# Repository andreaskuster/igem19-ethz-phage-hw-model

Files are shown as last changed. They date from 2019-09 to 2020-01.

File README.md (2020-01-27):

# iGEM ETHZ Logo iGEM ETH Zurich - iGEM 19 ETHZ Logo Libraries for Personalized Phage Therapy   

## Project Abstract
Antibiotic resistant pathogens are a major threat to global health. Emerging superbugs are rapidly becoming resistant to available antibiotics, while the discovery of new antibiotics is falling behind. Phage therapy offers a potential solution that has achieved remarkable successes. However, it is limited by the number of pathogens that can be targeted by available natural phages. To address this limitation, we aim to increase the range of phage specificities. Host specificity is influenced by the affinity of the phage’s binding protein to the bacterial surface. We developed a system that integrates random codons in phage genomes at any locus of interest. This allows for the formation of phage libraries with novel binding proteins that alter the host spectrum. Our bioreactor selects and evolves the best variants. The observed phage-host interactions can be used to further improve library design. Our system could be the basis for personalized treatment of bacterial infections. 
We are currently testing three approaches to generate these libraries.
* Yeast assembly: a plasmid containing the T7 genome is assembled by homologous recombination in yeast and a library of randomized oligos is inserted into variable region of tail fiber protein.
* Recombineering: A randomised sequence present on a plasmid is inserted into the tail fiber gene in vivo by using E. coli's homologous recombination machinery.
* In vitro: The tail fiber variable regions are ligated to the T7 genome in vitro by Gibson assembly. 

## Project Trailer
T007 - License to Lyse - iGEM 2019 ETH Zurich - Trailer (https://www.youtube.com/watch?v=lpeFW6eoZ5g?autoplay=1)

## Hardware Reactor Abstract
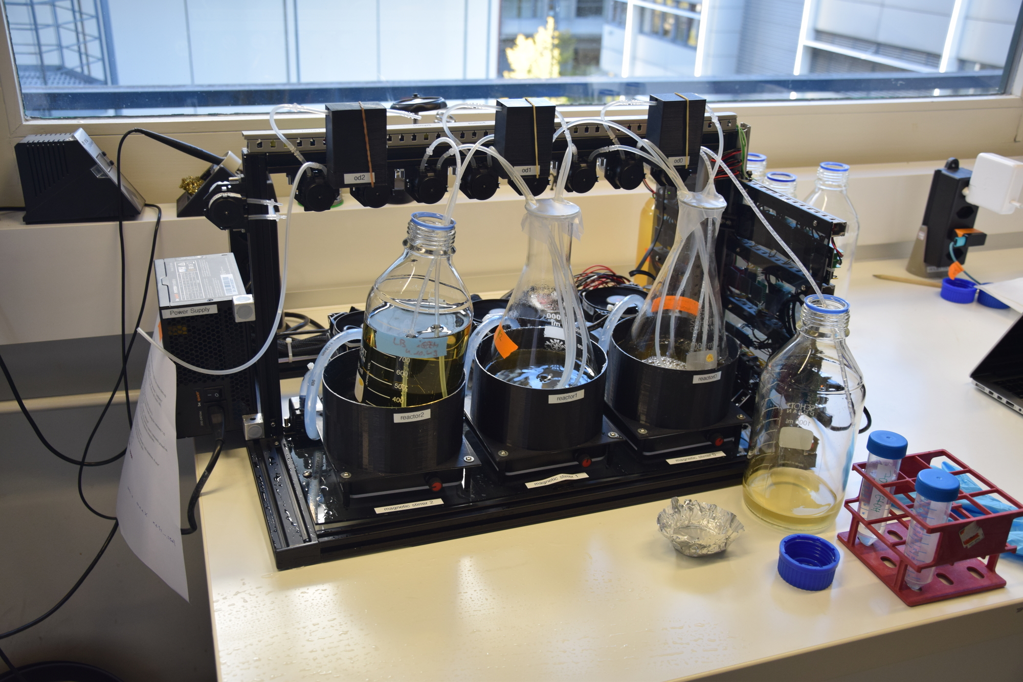
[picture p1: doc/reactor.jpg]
Hardware Reactor


To ensure the clinical relevance of our library, the rapid selection of the best phage variants is necessary and ensured by our bioreactor. Three flasks for cell growth each have integrated temperature control and peristaltic pumps on top of continuous OD measurement using our self-built OD sensors. This enables the cultivation of bacteria under controlled OD profiles. Real-time data from ongoing experiments is fed into our model to predict host concentrations and adjust growth conditions accordingly. User-friendly software allows the implementation of other experimental setups with custom parameters and monitoring mechanisms. Remote access and alerts permit long-term experiments. Our prototype was of great use for our own long-term and large volume experiments which led to multiple iterations of hardware and software improvements. To allow others to benefit from our design, we extensively documented the hardware and software. This bioreactor offers a cost-efficient solution to perform complex experimental designs with ease.

## Table of content
* [Case Study](#case-study-recombineering-library-experiment)
    * [Setup](#experiment-setup)
    * [Result](#result)
* [Hardware Reactor](#hardware-reactor)
    * [Hardware Overview](#hardware-overview)
    * [Hardware Components](#hardware-components)
    * [Software Overview](#software-overview)
        * [Online Optical Density Sensor](#)
        * [Reactor Temperature Control](#)
* [Software Model](#software-model)
    * [General](#general)
    * [Yeast Assembly](#phage-hw-model-1-yeast-assembly)
    * [Recombineering](#phage-hw-model-2-recombineering)

## Case Study: Recombineering Library Experiment
The goal of this case study is to show the reader a real-world usage scenario of the reactor system. Furthermore, it emphasizes the advantage of a fully automated and self-regulating experiment setup.

### Experiment Setup

Reactor Configuration

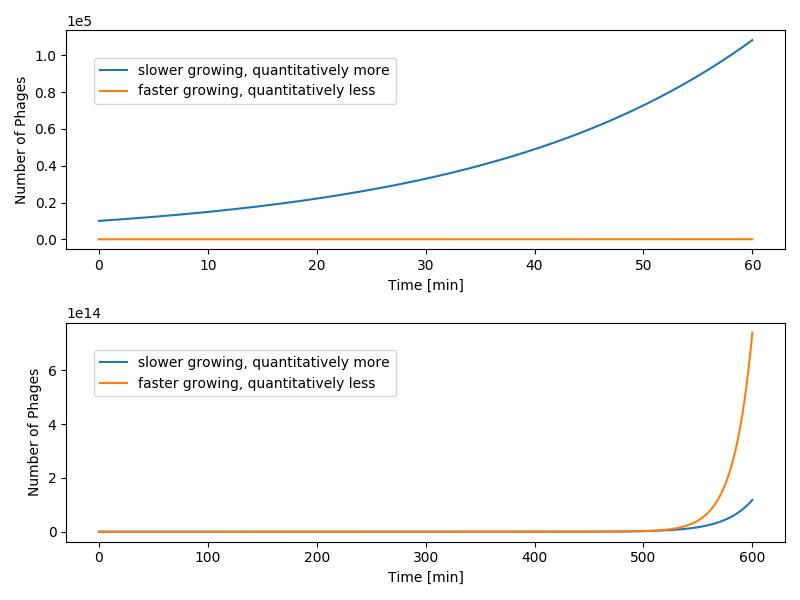
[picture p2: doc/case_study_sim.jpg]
Growth Simulation


### Result
 
Plate Result

## Software Model

### General

### Phage HW Model #1: Yeast Assembly
...
### Phage HW Model #2: Recombineering
...

## Hardware Reactor

### Hardware Overview
Reactor Hardware Overview

### Hardware Components

#### Computer: Raspberry Pi 3B+
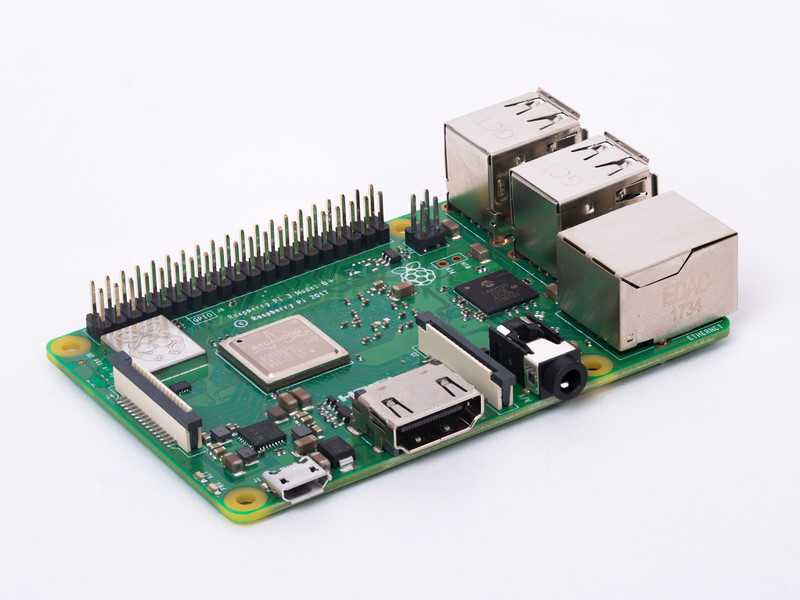
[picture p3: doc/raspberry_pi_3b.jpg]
Raspberry Pi 3B+


[Datasheet](hardware/devices/drivers/hw/datasheets/raspberry_pi_3b.pdf)
[Source](https://www.raspberrypi.org/)

#### Water Temperature Sensor: DS18B20
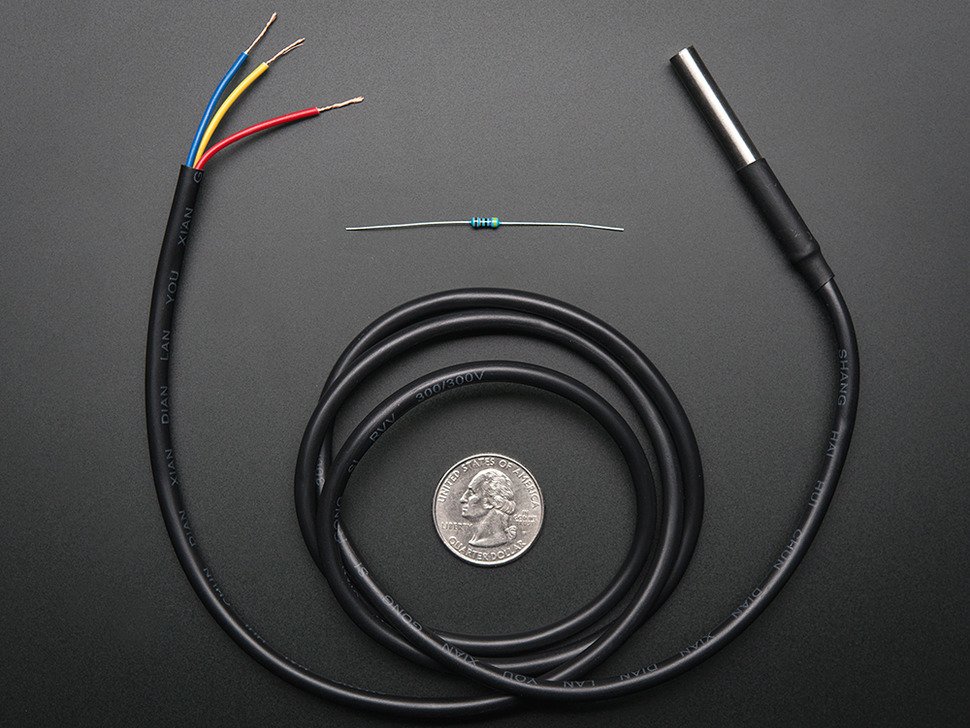
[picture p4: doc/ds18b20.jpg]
DS18B20


[Datasheet](hardware/devices/drivers/hw/datasheets/DS18B20.pdf)
[Source](https://www.adafruit.com/product/381)

#### Thermoelectric Peltier Element: TEC1-12715
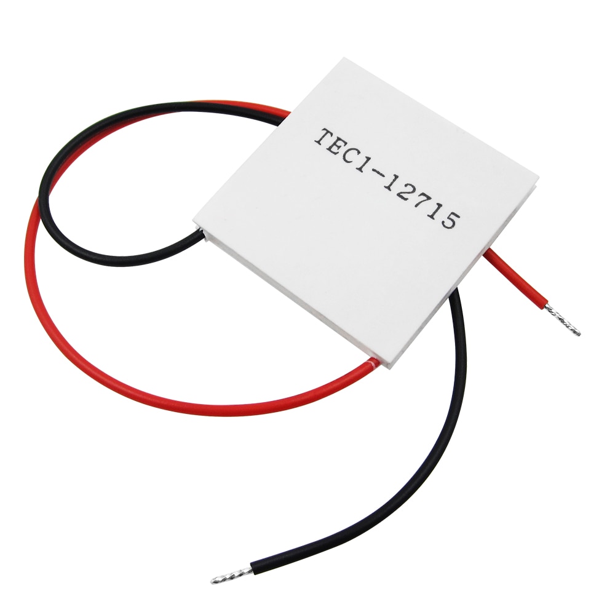
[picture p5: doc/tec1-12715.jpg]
TEC1-12715


[Datasheet](hardware/devices/drivers/hw/datasheets/TEC1_12715.pdf)
[Source](https://www.aliexpress.com/)

#### Electronic Speed Controller ESC
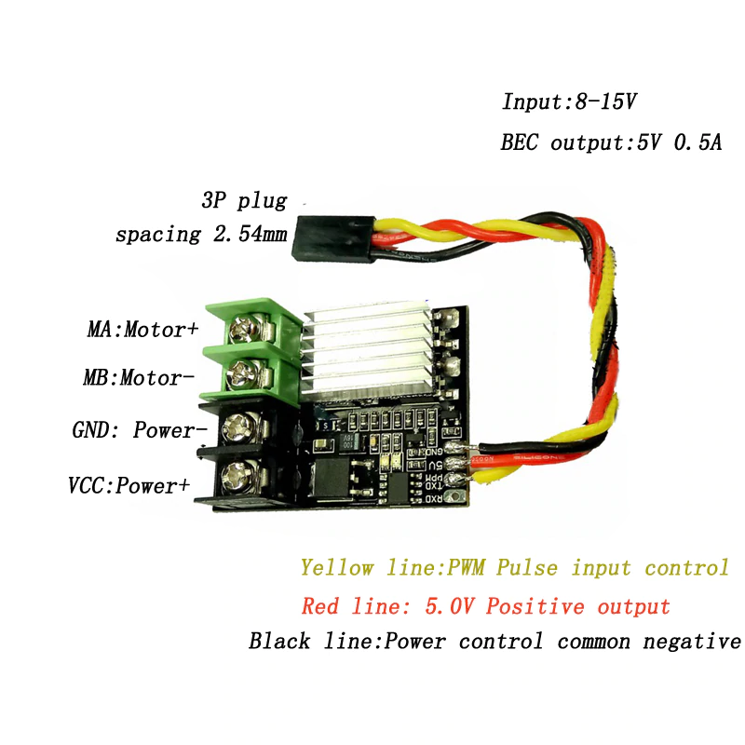
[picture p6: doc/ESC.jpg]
ESC


[Datasheet](hardware/devices/drivers/hw/datasheets/ESC.pdf)
[Source](https://www.aliexpress.com/)

#### Microprocessor: Arduino Nano
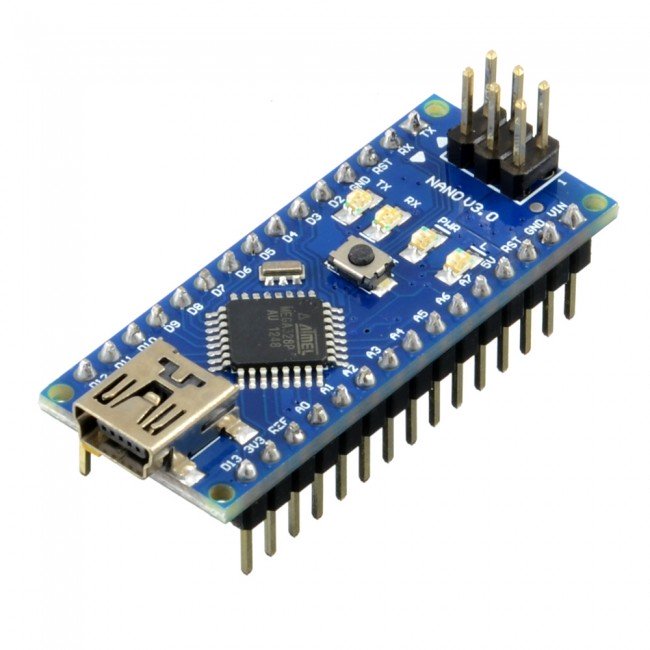
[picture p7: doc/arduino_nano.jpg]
Arduino Nano


[Datasheet](hardware/devices/drivers/hw/datasheets/a.pdf)
[Source](https://core-electronics.com.au/)

#### Ambient Temperature and Pressure Sensor: BME280
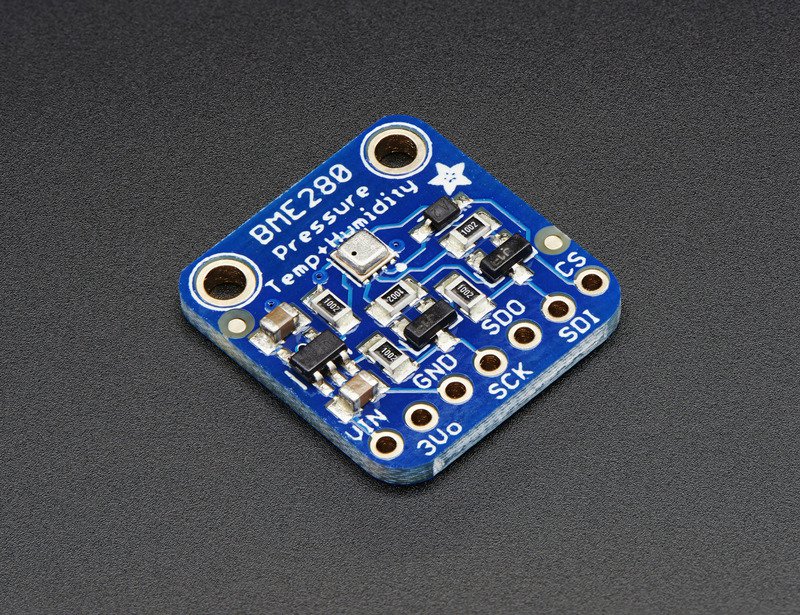
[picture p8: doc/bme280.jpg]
BME280


[Datasheet](hardware/devices/drivers/hw/datasheets/BME280.pdf)
[Source](https://learn.adafruit.com/adafruit-bme280-humidity-barometric-pressure-temperature-sensor-breakout)

#### 8 Channel Input/Output Port Extender: PCF8574
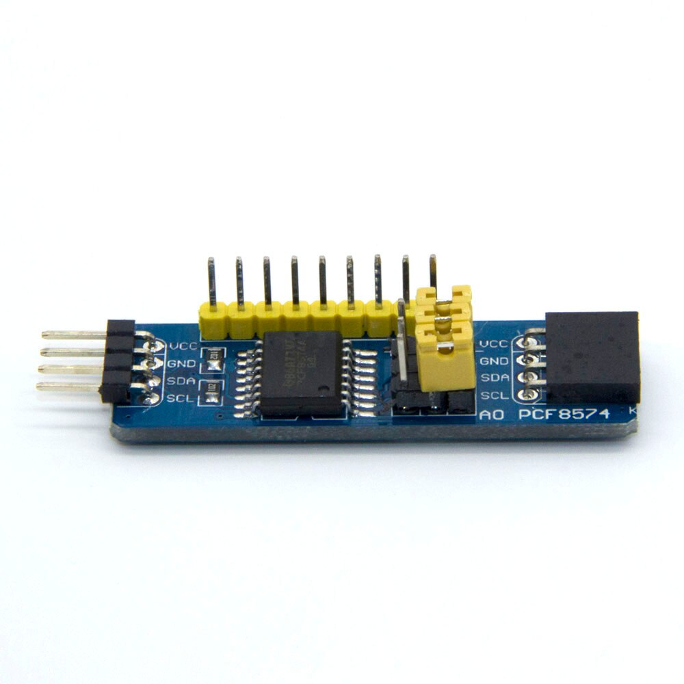
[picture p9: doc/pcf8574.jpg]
PCF8574


[Datasheet](hardware/devices/drivers/hw/datasheets/PCF8574.pdf)
[Source](https://www.aliexpress.com/)

#### Light Emitting Diode LED: TLCY5800
TLCY5800

[Datasheet](hardware/devices/drivers/hw/datasheets/TLCY5800.pdf)
[Source](https://www.distrelec.ch/de/led-gelb-mm-vishay-tlcy5800/p/30105848)

#### I2C Bus Multiplexer: TCA9548A
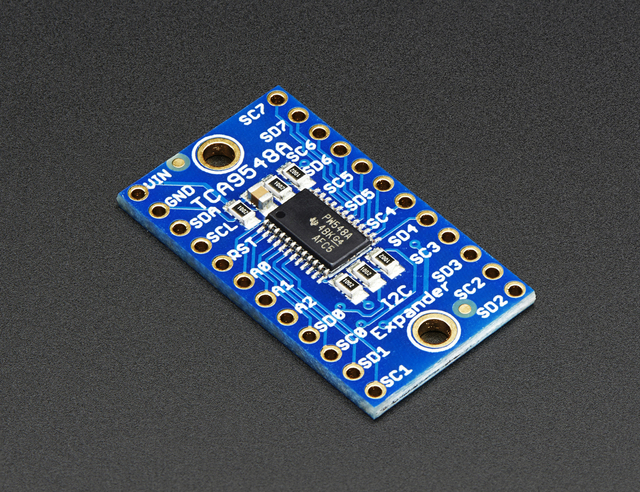
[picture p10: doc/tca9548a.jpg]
TCA9548A


[Datasheet](hardware/devices/drivers/hw/datasheets/TCA9448A.pdf)
[Source](https://learn.adafruit.com/adafruit-tca9548a-1-to-8-i2c-multiplexer-breakout/overview)

#### High Dynamic Range Digital Light Sensor: TSL2591
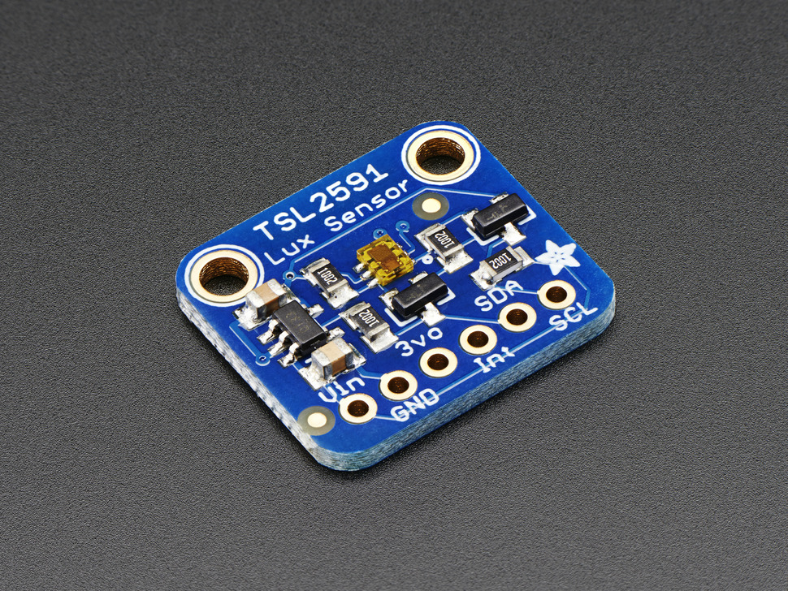
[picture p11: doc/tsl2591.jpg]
TSL2591


[Datasheet](hardware/devices/drivers/hw/datasheets/TSL2591.pdf)
[Source](https://www.adafruit.com/product/1980)

#### 16 Channel Pulse Width Modulation Module: PCA9685
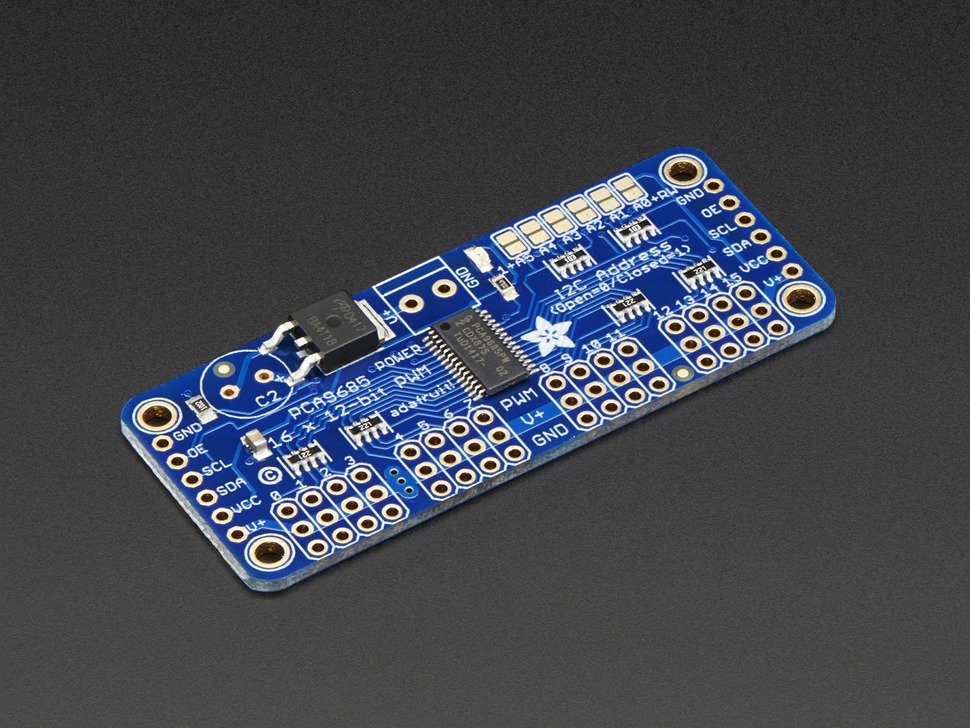
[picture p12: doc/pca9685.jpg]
PCA9685


[Datasheet](hardware/devices/drivers/hw/datasheets/PCA9685.pdf)
[Source](https://www.adafruit.com/product/815)

#### Optocoupler: TLP281
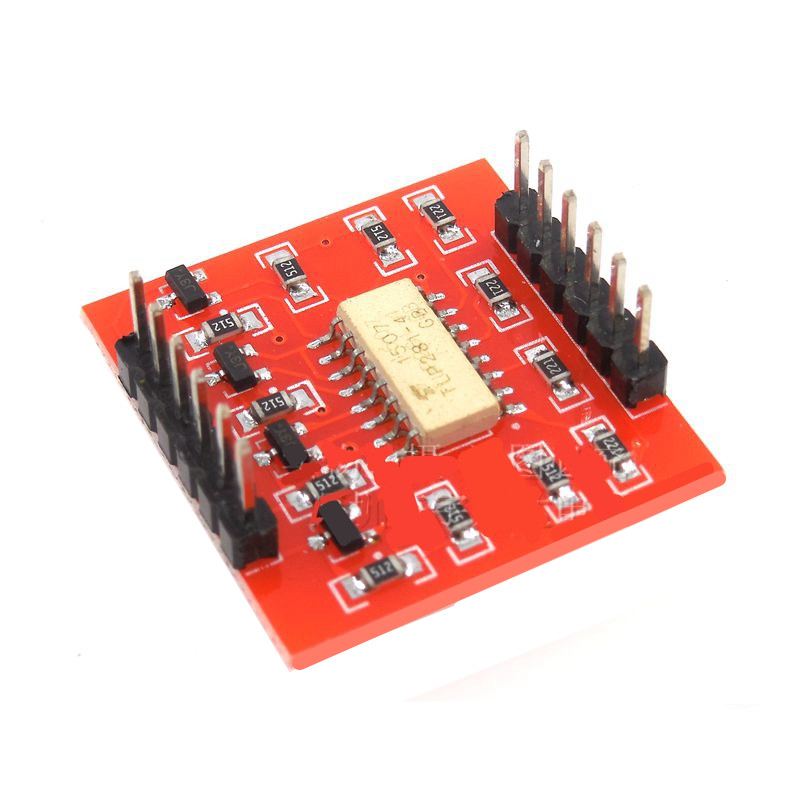
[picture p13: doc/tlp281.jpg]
TLP281


[Datasheet](hardware/devices/drivers/hw/datasheets/TLP281-4.pdf)
[Source](https://www.aliexpress.com/)

#### Magnetic Stirrer
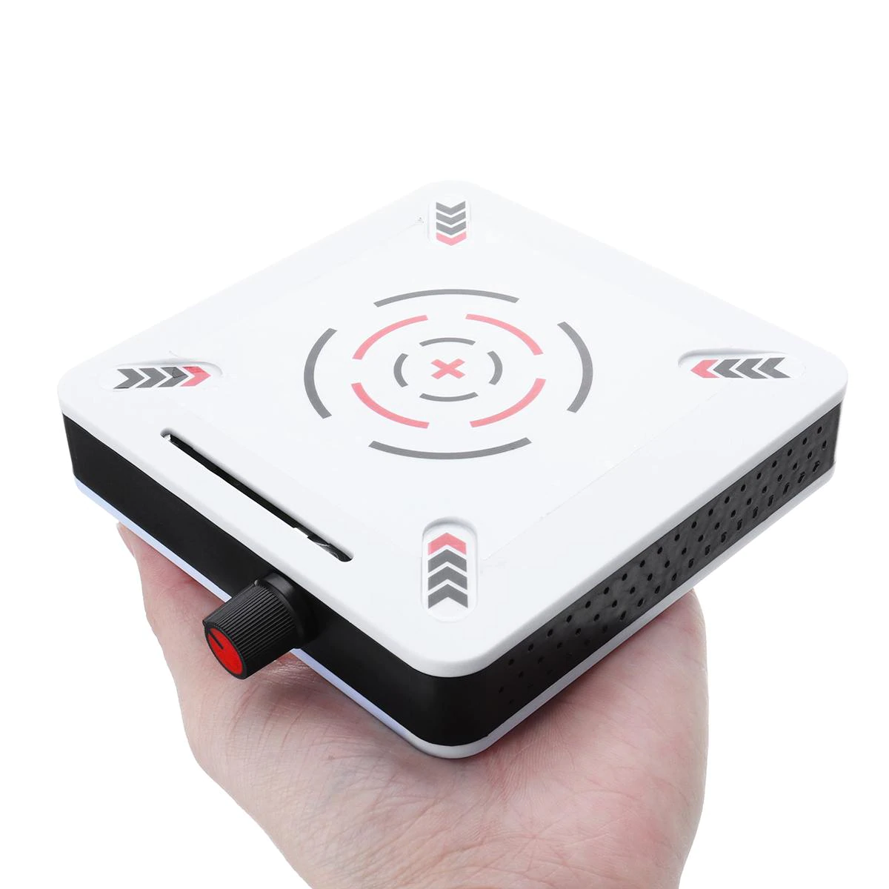
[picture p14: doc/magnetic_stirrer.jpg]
Magnetic Stirrer


[Datasheet](hardware/devices/drivers/hw/datasheets/magnetic_stirrer.pdf)
[Source](https://www.aliexpress.com/)

#### CPU PC Fan
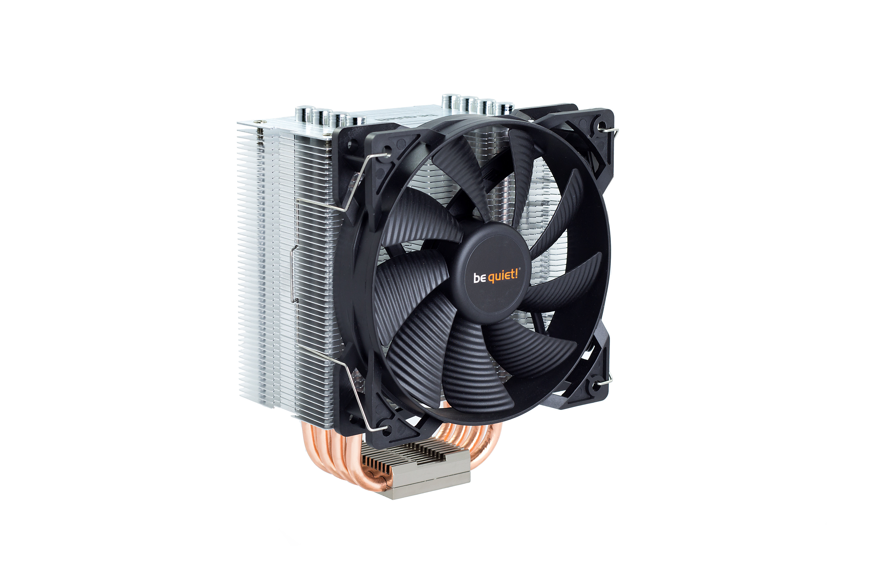
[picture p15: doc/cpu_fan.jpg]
CPU PC Fan


[Datasheet](hardware/devices/drivers/hw/datasheets/cpu_fan.pdf)
[Source](https://www.bequiet.com/en)

#### Water Pump
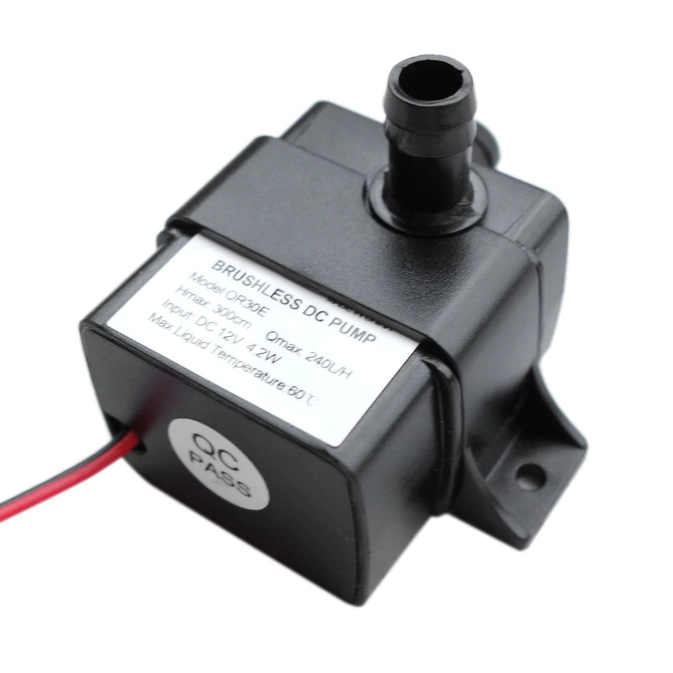
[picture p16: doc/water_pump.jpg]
Water Pump


[Datasheet](hardware/devices/drivers/hw/datasheets/water_pump.pdf)
[Source](https://www.aliexpress.com/)

#### Peristaltic Pump
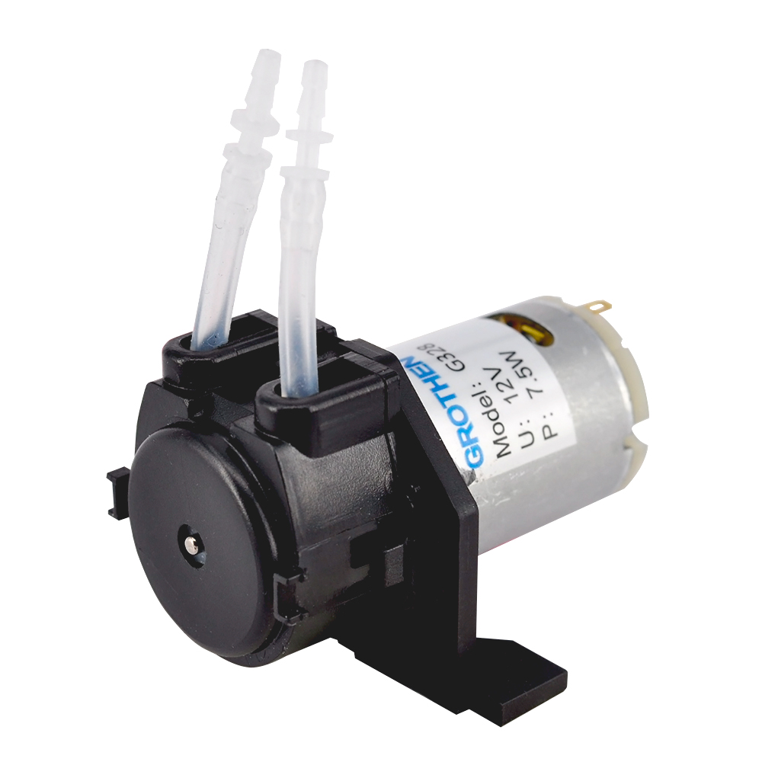
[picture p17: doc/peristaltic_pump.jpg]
Peristaltic Pump


[Datasheet](hardware/devices/drivers/hw/datasheets/peristaltic_pump.pdf)
[Source](https://www.aliexpress.com/)

#### Mosfet Transistor
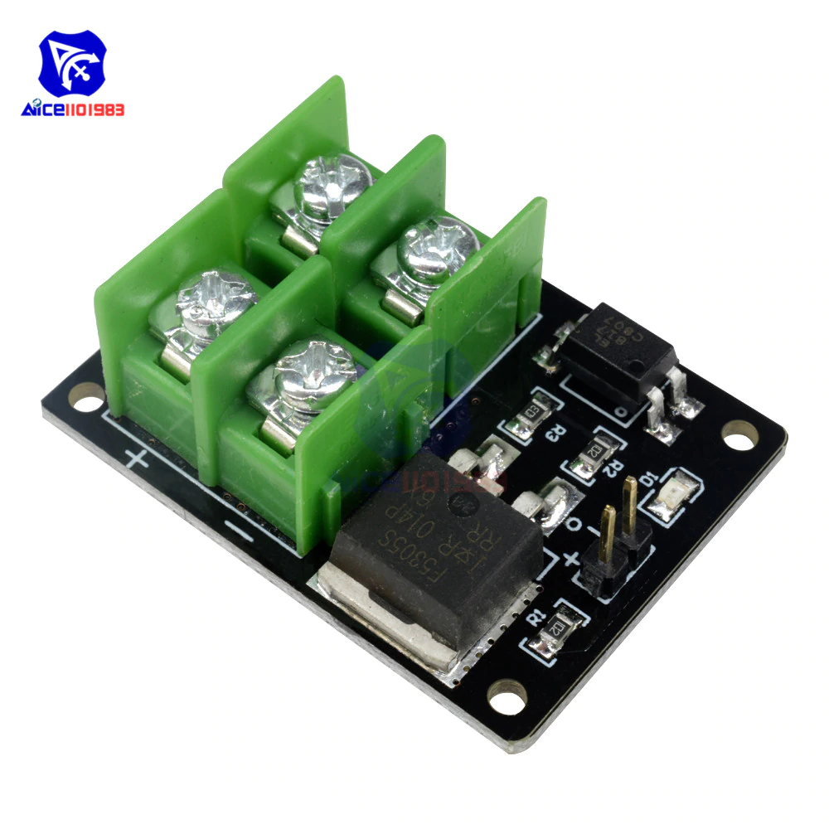
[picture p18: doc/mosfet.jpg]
Mosfet Transistor


[Datasheet](hardware/devices/drivers/hw/datasheets/mosfet.pdf)
[Source](https://www.aliexpress.com/)

#### Control Terminal

### Software Overview
Reactor Software Overview

### Devices
...

####  Online Optical Density Sensor
Optical Density Sensor
...

##### Calibration
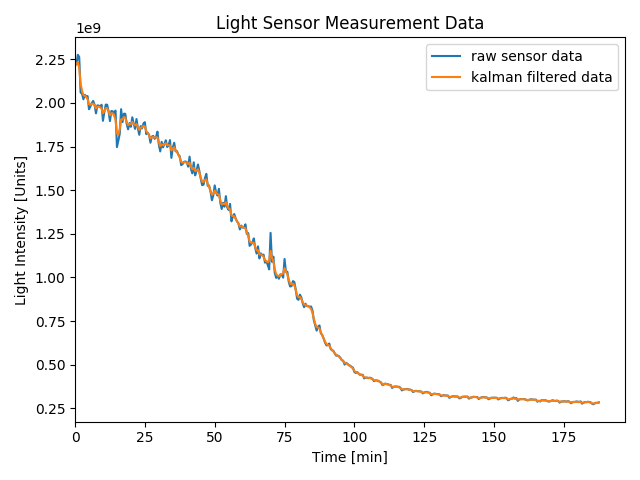
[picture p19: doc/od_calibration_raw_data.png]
Raw Sensor Data

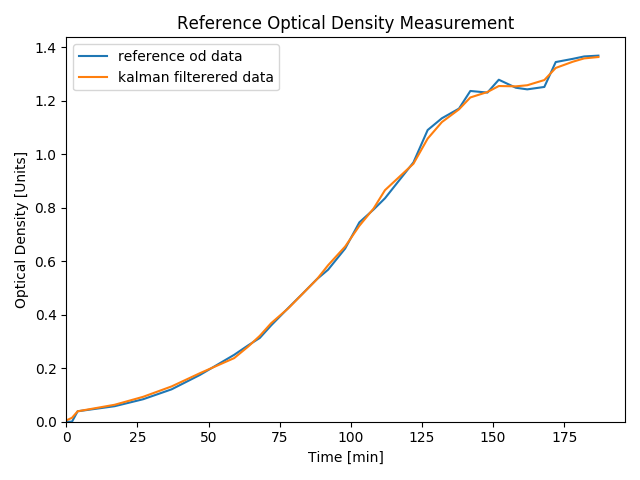
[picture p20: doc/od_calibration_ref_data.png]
Reference Data

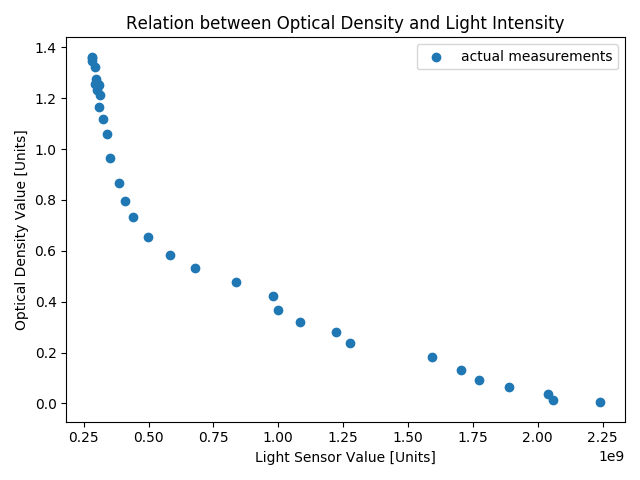
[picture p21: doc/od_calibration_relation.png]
Relation Light Sensor and OD

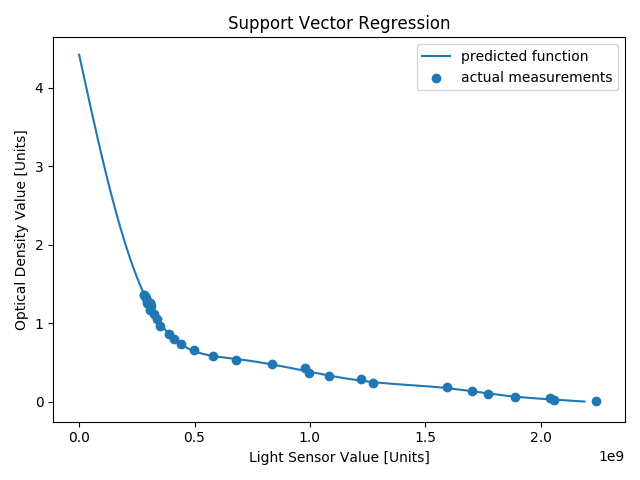
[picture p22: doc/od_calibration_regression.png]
Regression

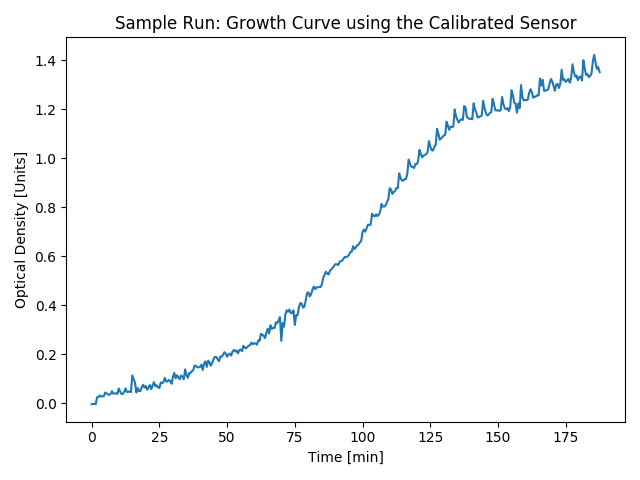
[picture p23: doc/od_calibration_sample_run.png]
Sample Run


#### Reactor Temperature Control
Temperature Control

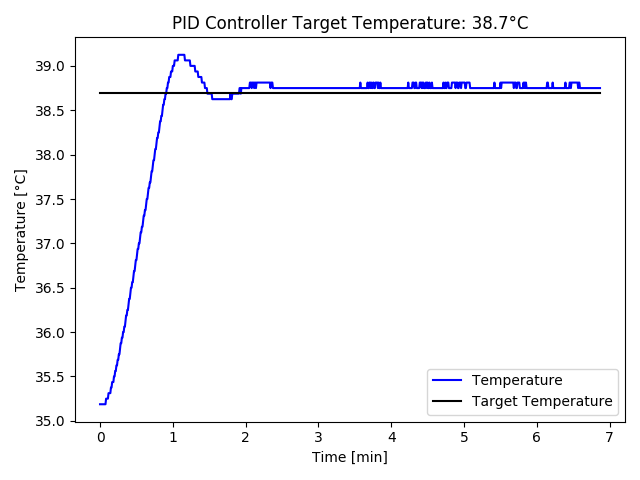
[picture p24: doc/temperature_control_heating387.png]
Reactor Heating

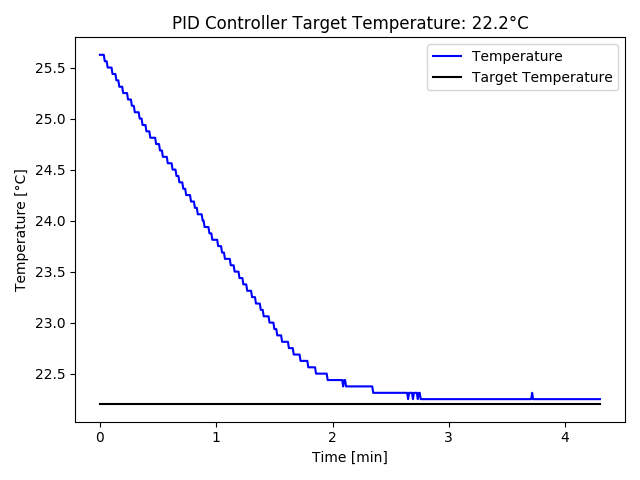
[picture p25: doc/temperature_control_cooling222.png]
Reactor Cooling


...

#### Peristaltic Pump
...

### Drivers
...

### HW
...

#### 1 Wire
...
* DS18B20

#### I2C
...
* BME280
* PCA9685
* PCF8574
* TCA9548A
* TSL2591

## Hardware Software Interaction
...

### Motivation

### Naive Constant Cell Density Controller

### Advanced Naive Constant Cell Density Controller

### Model Driven Constant Cell Density Controller

### Model Driven Constant Cell Denisty Controller with Fluorescent Original Host

## Usage
```
connect to the device:
1. plug in the power cable and switch on the power supply (the system starts up autoatically)
2. connect to the wifi network 'igem-ethz' (you should get an ip address from the DHCP server in the range 192.168.4.2-100)
3. connect to the server at address 192.168.4.1: (i.e. ssh pi@192.168.4.1)
 - username: pi
 - password: PASSWORD
4. change directory to igem19-ethz-phage-hw-model (i.e. cd igem19-ethz-phage-hw-model)
5. start the reactor software using the command: ./startup.sh
6. after the automatic device initialization, you should see all available commands printed to stdout
```

```
Commands
//TODO
```

```
fetch the whole repo:
git clone https://github.com/andreaskuster/igem19-ethz-phage-hw-model.git
```

```
update local repo to the most recent version:
git pull
```

```
keep the experiment running while disconnecting the computer:
- at startup, run: screen
- detach from session: Ctrl + a d
- attach to session: screen -r
```
```
connect to the graphical user interface:
1. connect to the wifi
2. use vnc viewer (realvnc)
 -address: 192.168.4.1
 -username: pi
```

## Raspberry Pi Setup
...

## 3D Print CAD Design

### Optical Density Sensor

### Water Bath

## Cleaning Procedure
* Pipes
    1. Rinse pipes using 70% ethanol
    2. Remove all pipes and autoclave them
    
* OD cuvettes
    1. one-way -> trash

* Reactor Flasks
    1. autoclave
    
 Additionally: do not mix phage-contaminated material with non-contaminated ones.

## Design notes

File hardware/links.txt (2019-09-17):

https://hackaday.com/tag/oversampling/
https://en.wikipedia.org/wiki/Oversampling
https://web.archive.org/web/20160318101005/http://www.paulallenengineering.com/blog/noise-oversampling-and-a-1-bit-adc

-> image noise: normal distributed https://en.wikipedia.org/wiki/Image_noise

https://github.com/denyssene/SimpleKalmanFilter

https://www.raspberrypi.org/documentation/configuration/wireless/access-point.md
https://learn.adafruit.com/16-channel-pwm-servo-driver/python-circuitpython
https://github.com/adafruit/Adafruit_Python_PCA9685/blob/master/examples/simpletest.py
https://learn.adafruit.com/adafruit-16-channel-servo-driver-with-raspberry-pi/using-the-adafruit-library
https://thepihut.com/blogs/raspberry-pi-tutorials/ds18b20-one-wire-digital-temperature-sensor-and-the-raspberry-pi

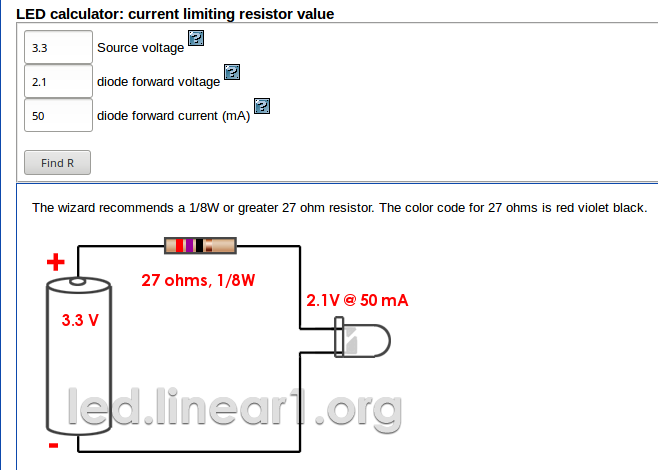
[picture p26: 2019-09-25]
hardware/devices/drivers/hw/led_resistor.png

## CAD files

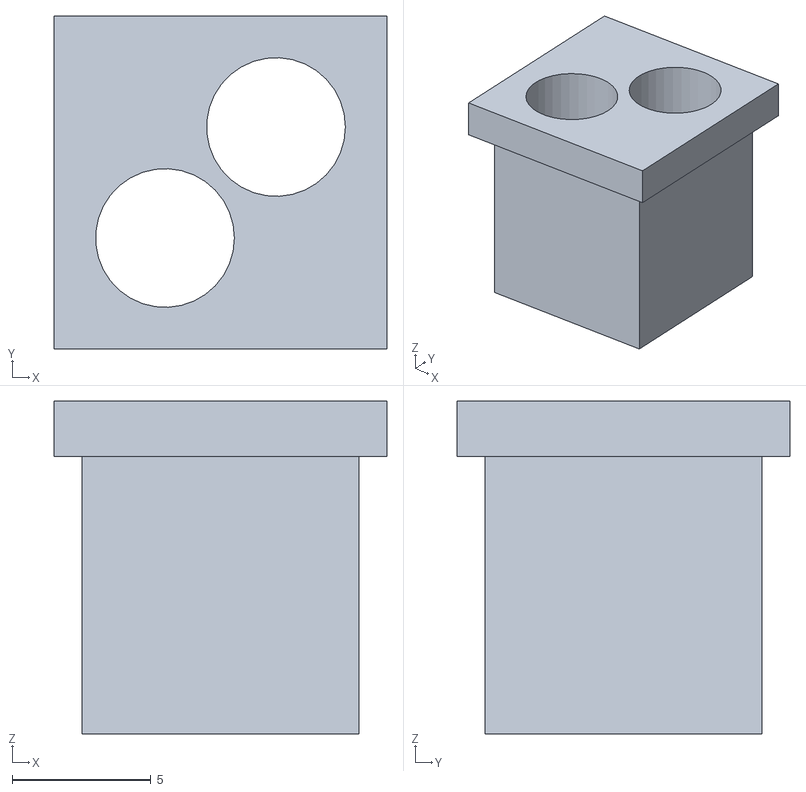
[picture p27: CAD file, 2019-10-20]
cad/cuvette_cover_v2.stl
12.0 x 12.0 x 12.0

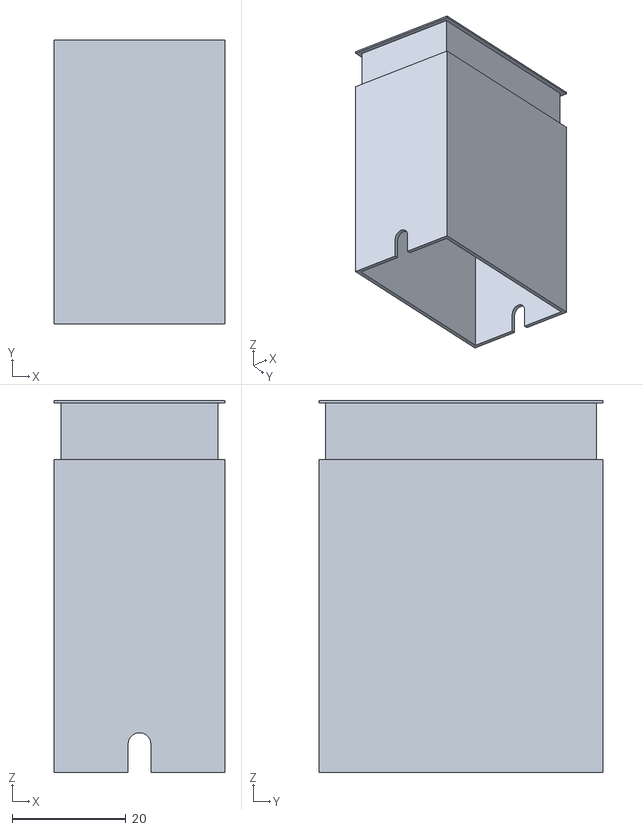
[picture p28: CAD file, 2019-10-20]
cad/od_middle_v5.stl
30.0 x 50.0 x 65.4

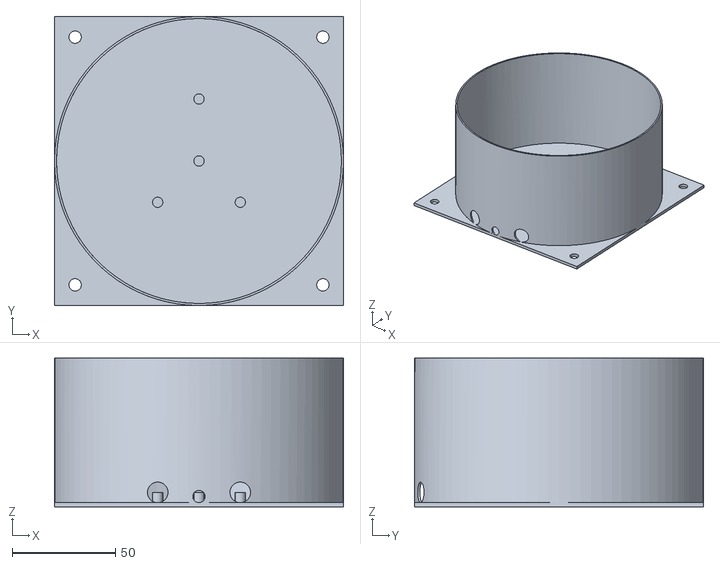
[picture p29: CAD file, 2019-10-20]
cad/erlenmeyer_stand_v1.stl
140.0 x 140.0 x 72.0

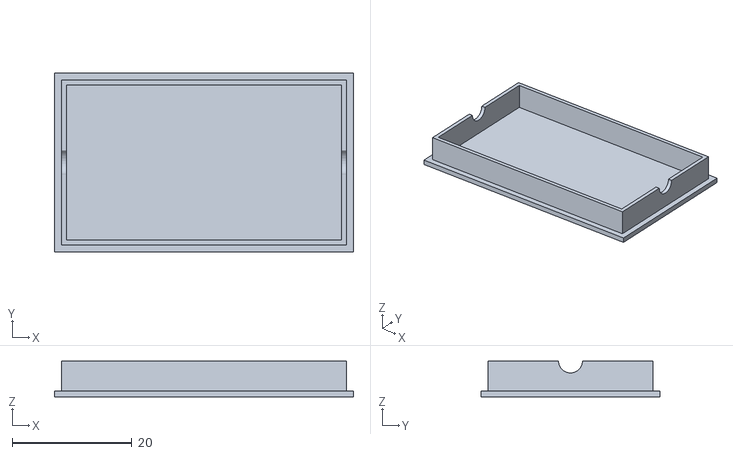
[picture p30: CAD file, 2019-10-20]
cad/od_top_v5.stl
50.0 x 30.0 x 6.00

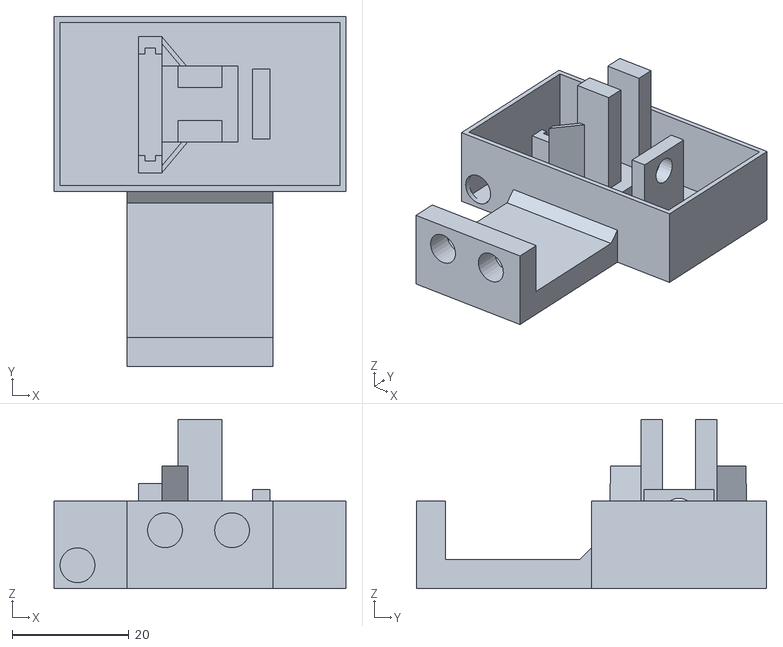
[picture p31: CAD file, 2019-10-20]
cad/od_bottom_tsl2591_v5.stl
50.0 x 60.0 x 29.0

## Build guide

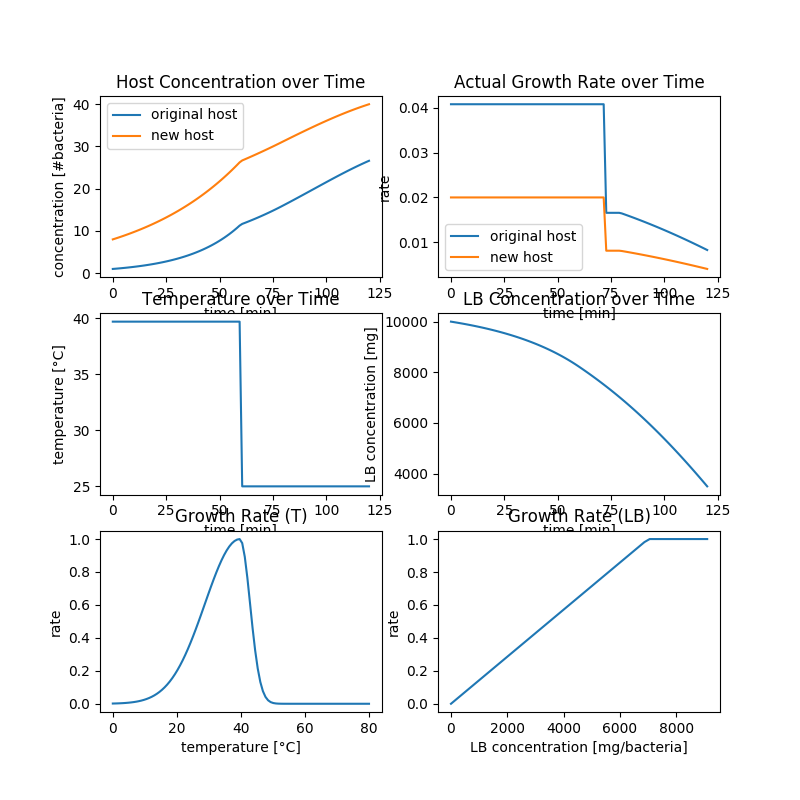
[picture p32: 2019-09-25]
yeast_assembly/example.png

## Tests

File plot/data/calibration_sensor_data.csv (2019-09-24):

2.238550566000000000e+09
2.219856255000000000e+09
2.276168688000000000e+09
2.263847920750000000e+09
2.059244528000000000e+09
2.053739504000000000e+09
2.021298927500000000e+09
2.046530544000000000e+09
2.038584304000000000e+09
2.039174128000000000e+09
1.964052625937500000e+09
1.979675057687500000e+09
2.000393200937500000e+09
2.011685872000000000e+09
1.989841904125000000e+09
1.940557788000000000e+09
1.986269934000000000e+09
1.984992240000000000e+09
1.978307568625000000e+09
1.989972976000000000e+09
1.897959398000000000e+09
1.948869166250000000e+09
1.990824944000000000e+09
1.989796848000000000e+09
1.953010672062500000e+09
1.896411241000000000e+09
1.954226863375000000e+09
1.951962096812500000e+09
1.944249328000000000e+09
1.956348912000000000e+09
1.747374443625000000e+09
1.783845872000000000e+09
1.823429226750000000e+09
1.964479472937500000e+09
1.890620400562500000e+09
1.938723824187500000e+09
1.937740784000000000e+09
1.880003568000000000e+09
1.848979753125000000e+09
1.884807600000000000e+09
1.863430959625000000e+09
1.918014448000000000e+09
1.881117680812500000e+09
1.851606000000000000e+09
1.908052976000000000e+09
1.855296496000000000e+09
1.817493807312500000e+09
1.867452913000000000e+09
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

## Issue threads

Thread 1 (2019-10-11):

Output of delay differential equation system not as expected

andreaskuster, 2019-10-11:
The simulation with our system of delay differential equations (to model the phages from infection to the burst of the cell) is broken in the current implementation.
(1) The simulation result does not behave as expected. (I will review your code for any bugs, You should do this too.)
(2) From my understanding, JiTCDDE does not support piecewise defined function (we could use a sharp sigmoidal function, but this makes thinks more complicated and is kind of hackish). This is a mandatory requirement i.e. for defining 'sharp' temperature profiles. I will have a look for a different library that natively supports this.

andreaskuster, 2019-10-11:
i found ```ddeint```, a python library with all our required capabilities. Please update your implementation to be compatible with ddeint. I wrote a small getting started example for you:
```
import numpy as np
from ddeint import ddeint
from pylab import array, sin, linspace, subplots

tau = 30.0

def foo(t):
    if t < 10.0:
        return 0.0
    elif 10.0 <= t < 10.0 * np.pi:
        return 1.0
    else:
        return 10.0 * sin(t * 0.5)

def values_before_zero(t):
    return array([0.0, 0.0])

def model(Y, t):
    x, y = Y(t)
    x_tau, y_tau = Y(t - tau)
    return array([foo(t), x_tau])

tt = linspace(0, 100, 1000)
yy = ddeint(model, values_before_zero, tt)

fig, ax = subplots(1, figsize=(8, 4))

ax.plot(tt, [x[0] for x in yy], label="trace1")
ax.plot(tt, [x[1] for x in yy], label="trace2")
fig.legend(loc='upper center', borderaxespad=2.0)
fig.show()
```

The function ```foo(t)``` is a piecewise defined and the delay differential equation ```trace2``` looks plausible (30ish units 'behind' ```foo(t)```).

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

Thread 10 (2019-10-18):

OD Sensor: Set minimum od value to zero.

andreaskuster, 2019-10-18:
The SVM regression does not know how to handle measurements value above the maximum value it knows from the training data. We therefore manually set od values to 0.0 in case the light sensor value is higher than the maximum training data sample.

Closed 2019-10-19.

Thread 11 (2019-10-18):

Write log directly to csv.

andreaskuster, 2019-10-18:
The current implementation stores all measurements in lists and saves them to the file in the finalization routine. Therefore, improper disconnects (i.e. connection loss) could lead to the loss of the log data. We can fix this by directly appending the data to the file after the measurement.

Closed 2019-10-19.

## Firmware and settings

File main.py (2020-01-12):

#!/usr/bin/env python3
# encoding: utf-8

"""
    Copyright (C) 2019-2020  Andreas Kuster

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
__author__ = "Andreas Kuster"
__copyright__ = "Copyright 2019-2020"
__license__ = "GPL"


import os
import select
import sys
import threading
import time
import numpy as np
from typing import List
import json

sys.path.append(os.path.join(os.path.dirname(__file__), "hardware"))
sys.path.append(os.path.join(os.path.dirname(__file__), "hardware/devices"))
sys.path.append(os.path.join(os.path.dirname(__file__), "hardware/devices/drivers/hw/i2c"))

from devices.OpticalDensitySensor import OpticalDensitySensor
from devices.PeristalticPump import PeristalticPump
from devices.ReactorTemperatureControl import ReactorTemperatureControl

_PUMP_MAP = {
    "pump0": 0,
    "pump1": 1,
    "pump2": 2,
    "pump3": 3,
    "pump4": 4,
    "pump5": 5,
    "pump6": 6,
    "pump7": 7,
    "pump8": 8
}

_REACTOR_MAP = {
    "reactor0": 0,
    "reactor1": 1,
    "reactor2": 2
}

_SENSOR_MAP = {
    "od0": 0,
    "od1": 1,
    "od2": 2
}


def print_help():
    print("usage: reactor.py command arg0 arg1 ..")
    print("required: command")
    print()
    print("example commands:")
    # temperature control
    print("set temperature reactor0 39.0 // [°C]")
    print("disable temperature reactor0")
    # peristaltic pumps
    print("enable pump0")
    print("set speed pump0 100 // [%]")
    print("disable pump0")
    # print("set volume pump0 50 // [ml]") TODO: not implemented yet
    # od sensor
    print("enable sensor od0")
    print("disable sensor od0")
    # controller
    print("enable controller reactor0 reactor1 od0 pump8 pump6 pump5 0.5 // target od")
    print("disable controller")
    print()


def output_info_event_loop(reactors: List[ReactorTemperatureControl], sensors: List[OpticalDensitySensor],
                           pumps: List[PeristalticPump], interval):
    starttime = time.time()
    while True:
        print()
        print("Bioreactor State Report:")
        for reactor in reactors:
            if reactor.enabled:
                reactor.info()
        for sensor in sensors:
            if sensor.enabled:
                sensor.info()
        for pump in pumps:
            if pump.enabled:
                pump.info()
        time.sleep(interval - ((time.time() - starttime) % interval))


def temperature_event_loop(reactors: List[ReactorTemperatureControl], interval):
    starttime = time.time()
    while True:
        for reactor in reactors:
            reactor.control_loop()
        time.sleep(interval - ((time.time() - starttime) % interval))


def od_sensor_event_loop(sensor: OpticalDensitySensor, interval):
    starttime = time.time()
    while True:
        sensor.event_loop()
        time.sleep(interval - ((time.time() - starttime) % interval))






class NaiveConstantConcentration:

    def __init__(self,
                 enabled: bool,
                 target_od: float,
                 reactors: List[ReactorTemperatureControl],
                 sensors: List[OpticalDensitySensor],
                 pumps: List[PeristalticPump]):
        """
        :param enabled: enable / disable control loop
        :param reactors: reactor[0] = bacteria only (control constant growth rate), reactor[2] = bacteria & phages
        :param sensors: sensor[0] = sensor for reactor[0], sensor[1]  = sensor for reactor[2]
        :param pumps: pump[0] = lb influx to reactor[0], pump[1] = pump from reactor[0] to reactor[1], pump[3] = from reactor[1] to the waste
        :param interval: control loop interval
        """
        self.enabled = enabled
        self.target_od = target_od
        self.reactors = reactors
        self.sensors = sensors
        self.pumps = pumps
        self.tol = 0.0
        timestamp = time.strftime("%Y-%m-%d_%H:%M:%S")
        self.file = "log/{}_growth_rate.csv".format(timestamp)
        self.pump_time = 20.0

    def control_loop(self):
        if self.enabled:
            start_val = self.sensors[0].last_od
            diff = self.sensors[0].last_od - (self.target_od + self.tol)
            if diff > 0.0:  # too high, pump out
                self.pumps[0].enable()
                self.pumps[1].enable()
                self.pumps[2].enable()
                time.sleep(self.pump_time)
                self.pumps[0].disable()
                self.pumps[1].disable()
                self.pumps[2].disable()
                print("pump")
            else:
                print("not pumping")
            # append log and write data point to file
            timestamp = time.strftime("%Y-%m-%d_%H:%M:%S")
            with open(self.file, "a") as myfile:
                myfile.write("{},{},{}\n".format(timestamp, start_val, self.pump_time if (diff > 0.0) else 0.0))

    def disable(self):
        self.enable = False
        self.finalize()

    def finalize(self):
        for pump in self.pumps:
            pump.disable()
        for sensor in self.sensors:
            sensor.disable()
        for reactor in self.reactors:
            reactor.disable()


def naive_constant_concentration(configuration: NaiveConstantConcentration, interval):
    starttime = time.time()
    while True:
        configuration.control_loop()
        time.sleep(interval - ((time.time() - starttime) % interval))


def advanced_naive_constant_concentration(configuration: AdvancedNaiveConstantConcentration, interval):
    starttime = time.time()
    while True:
        configuration.control_loop()
        time.sleep(interval - ((time.time() - starttime) % interval))


if __name__ == "__main__":

    print("Instantiate devices and intialize them.")

    # instantiate locks
    i2c_lock = threading.Lock()
    one_wire_lock = threading.Lock()

    # instantiate all devices
    reactor_temperature = [
        ReactorTemperatureControl(id=0,
                                  i2c_lock=i2c_lock,
                                  one_wire_lock=one_wire_lock,
                                  target_temperature=25.0,
                                  enabled=False,
                                  verbose=False),
        ReactorTemperatureControl(id=1,
                                  i2c_lock=i2c_lock,
                                  one_wire_lock=one_wire_lock,
                                  target_temperature=25.0,
                                  enabled=False,
                                  verbose=False),
        ReactorTemperatureControl(id=2,
                                  i2c_lock=i2c_lock,
                                  one_wire_lock=one_wire_lock,
                                  target_temperature=25.0,
                                  enabled=False,
                                  verbose=False),
    ]
    temperature_event_loop_thread = threading.Thread(target=temperature_event_loop, args=(reactor_temperature, 2.0,),
                                                     daemon=True)

    od_sensor = [
        OpticalDensitySensor(
            id=0,
            i2c_lock=i2c_lock,
            enabled=False,
            verbose=False
        ),
        OpticalDensitySensor(
            id=1,
            i2c_lock=i2c_lock,
            enabled=False,
            verbose=False
        ),
        OpticalDensitySensor(
            id=2,
            i2c_lock=i2c_lock,
            enabled=False,
            verbose=False
        )
    ]
    od_sensor0_event_loop_thread = threading.Thread(target=od_sensor_event_loop, args=(od_sensor[0], 30.0,),
                                                    daemon=True)
    od_sensor1_event_loop_thread = threading.Thread(target=od_sensor_event_loop, args=(od_sensor[1], 30.0,),
                                                    daemon=True)
    od_sensor2_event_loop_thread = threading.Thread(target=od_sensor_event_loop, args=(od_sensor[2], 30.0,),
                                                    daemon=True)

    pumps = [
        PeristalticPump(
            id=0,
            i2c_lock=i2c_lock,
            enabled=False,
            verbose=False),
        PeristalticPump(
            id=1,
            i2c_lock=i2c_lock,
            enabled=False,
            verbose=False),
        PeristalticPump(
            id=2,
            i2c_lock=i2c_lock,
            enabled=False,
            verbose=False),
        PeristalticPump(
            id=3,
            i2c_lock=i2c_lock,
            enabled=False,
            verbose=False),
        PeristalticPump(
            id=4,
            i2c_lock=i2c_lock,
            enabled=False,
            verbose=False),
        PeristalticPump(
            id=5,
            i2c_lock=i2c_lock,
            enabled=False,
            verbose=False),
        PeristalticPump(
            id=6,
            i2c_lock=i2c_lock,
            enabled=False,
            verbose=False),
        PeristalticPump(
            id=7,
            i2c_lock=i2c_lock,
            enabled=False,
            verbose=False),
        PeristalticPump(
            id=8,
            i2c_lock=i2c_lock,
            enabled=False,
            verbose=False)
    ]

    output_info_event_loop_thread = threading.Thread(target=output_info_event_loop,
                                                     args=(reactor_temperature, od_sensor,
                                                           pumps, 30.0,), daemon=True)
    controller1: NaiveConstantConcentration = NaiveConstantConcentration(
        enabled=False,
        reactors=None,
        sensors=None,
        pumps=None,
        target_od=0.5
    )
    naive_constant_concentration_thread = threading.Thread(target=naive_constant_concentration,
                                                           args=(controller1, 30.0), daemon=True)

    controller2: AdvancedNaiveConstantConcentration = AdvancedNaiveConstantConcentration(
        enabled=False,
        reactors=None,
        sensors=None,
        pumps=None,
        target_od=0.5,
        continuous_pump_time=2.0
    )
    advanced_naive_constant_concentration_thread = threading.Thread(target=advanced_naive_constant_concentration,
                                                                    args=(controller2, 10.0), daemon=True)

    print("start deamon threads")
    # start background event loops
    temperature_event_loop_thread.start()
    od_sensor0_event_loop_thread.start()
    od_sensor1_event_loop_thread.start()
    od_sensor2_event_loop_thread.start()
    output_info_event_loop_thread.start()
    naive_constant_concentration_thread.start()
    advanced_naive_constant_concentration_thread.start()

    try:
        print("run input loop")
        print_help()
        while True:
            if select.select([sys.stdin, ], [], [], 0.0)[0]:  # check if input is available
                for line in sys.stdin:  # read lines

                    command = line.split()  # split command into components

                    # go through all command queries
                    try:
                        if len(command) == 0 or command[0] == "help":
                            print_help()
                        elif command[0] == "enable":
                            if command[1] == "sensor":
                                od_sensor[_SENSOR_MAP[command[2]]].enable()
                            elif command[1] == "controller":
                                controller1.reactors = [
                                    reactor_temperature[_REACTOR_MAP[command[2]]],
                                    reactor_temperature[_REACTOR_MAP[command[3]]]
                                ]
                                controller1.sensors = [od_sensor[_SENSOR_MAP[command[4]]]]
                                controller1.pumps = [pumps[_PUMP_MAP[command[5]]],
                                                     pumps[_PUMP_MAP[command[6]]],
                                                     pumps[_PUMP_MAP[command[7]]]]
                                controller1.target_od = float(command[8])
                                controller1.enabled = True
                                print("Command accepted.")
                            elif command[1] == "advanced":
                                controller2.reactors = [
                                    reactor_temperature[_REACTOR_MAP[command[2]]],
                                    reactor_temperature[_REACTOR_MAP[command[3]]]
                                ]
                                controller2.sensors = [od_sensor[_SENSOR_MAP[command[4]]]]
                                controller2.pumps = [pumps[_PUMP_MAP[command[5]]],
                                                     pumps[_PUMP_MAP[command[6]]],
                                                     pumps[_PUMP_MAP[command[7]]],
                                                     pumps[_PUMP_MAP[command[8]]]]
                                controller2.target_od = float(command[9])
                                controller2.continuous_pump_time = float(command[10])
                                controller2.enabled = True
                                print("Command accepted.")
                            else:
                                pumps[_PUMP_MAP[command[1]]].enable()
                            print("Command accepted.")
                        elif command[0] == "disable":
                            if command[1] == "temperature":
                                reactor_temperature[_REACTOR_MAP[command[2]]].disable()
                            elif command[1] == "sensor":
                                od_sensor[_SENSOR_MAP[command[2]]].disable()
                            elif command[1] == "controller":
                                controller1.disable()
                            elif command[1] == "advanced":
                                controller2.enabled = False
                            else:
                                pumps[_PUMP_MAP[command[1]]].disable()
                            print("Command accepted.")
                        elif command[0] == "set":
                            if command[1] == "temperature":
                                reactor_temperature[_REACTOR_MAP[command[2]]].set_target_temperature(float(command[3]))
                                reactor_temperature[_REACTOR_MAP[command[2]]].enable()
                            elif command[1] == "speed":
                                pumps[_PUMP_MAP[command[2]]].set_speed(int(command[3]))
                            elif command[1] == "volume":
                                pumps[_PUMP_MAP[command[2]]].set_volume(int(command[3]))
                            print("Command accepted.")
                        else:
                            print_help()
                    except Exception as ex:
                        print("Invalid syntax, try again.")
                        print(ex)

            time.sleep(0.5)

    except KeyboardInterrupt:
        print("Exiting...but first put all devices into a safe state...")
    finally:
        # save log files: TODO
        # put all devices into a safe idle state
        for sensor in od_sensor:
            sensor.finalize()
        for pump in pumps:
            pump.finalize()
        for temp in reactor_temperature:
            temp.finalize()
        print("Goodbye.")

# https://docs.python.org/2/library/threading.html#using-locks-conditions-and-semaphores-in-the-with-statement
# https://stackoverflow.com/questions/3762881/how-do-i-check-if-stdin-has-some-data

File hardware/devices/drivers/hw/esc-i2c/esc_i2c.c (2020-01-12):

/*
    Copyright (C) 2019-2020  Andreas Kuster

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
    You should have received a copy of the GNU General Public License
    along with this program.  If not, see <http://www.gnu.org/licenses/>.
*/

#include <Servo.h>
#include<Wire.h>

/*
    Arduino ESC I2C Controller

    This device listens at address 77 on the i2c bus and sends PPM signals to the ESC controller for temperature control.
*/

// instantiate the servo object modules
Servo ESC0;
Servo ESC1;
Servo ESC2;

// i2c data receive event handler
void receiveEvent (int bytes) {

    // check if received data has correct length
    if(bytes == 2) {

        // read values of the tuple (device id, control value)
        byte device = Wire.read();

        // map value from [0, 200] to [1500, 2000]
        int value = map(Wire.read(), 0, 200, 150, 200);
        value *= 10;

        // choose the device according to the id
        switch(device){
            case 0:
                // send PPM value to ESC1
                ESC0.writeMicroseconds(value);
                break;
            case 1:
                // send PPM value to ESC2
                ESC1.writeMicroseconds(value);
                break;
            case 2:
                // send PPM value to ESC3
                ESC2.writeMicroseconds(value);
                break;
        }

         // print received control command
         Serial.print("device:");
         Serial.print(device);
         Serial.print(" value:");
         Serial.print(value);
         Serial.println();
    } else {

        // false length: read all and void
        for(int i = 0; i < bytes; i++){
            Wire.read();
        }
        Serial.println("wrong length, discard data");
    }
}

void setup() {

    // start serial debug output
    Serial.begin(9600);
    Serial.println("start device");

    // init esc controller
    Serial.println("init esc");
    ESC0.attach(9);
    ESC1.attach(10);
    ESC2.attach(11);
    ESC0.writeMicroseconds(1750);
    ESC1.writeMicroseconds(1750);
    ESC2.writeMicroseconds(1750);

    // start i2c slave at address 7
    Serial.println("init i2c");
    Wire.begin(7);
    Wire.onReceive(receiveEvent);

    // give the escs some time to set up
    Serial.println("wait for esc");
    delay(2000);

    // ready
    Serial.println("ready");
}

void loop() {
    // do nothing
}

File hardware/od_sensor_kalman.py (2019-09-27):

from pykalman import KalmanFilter
import numpy as np
import matplotlib.pyplot as plt


data = np.genfromtxt('/home/andreas/PycharmProjects/igem19-ethz-phage-hw-model/hardware/data/od.csv', delimiter=',')
x = np.arange(len(data))



kf = KalmanFilter(initial_state_mean=2200000000, n_dim_obs=1)
(mean, covariance) = kf.filter(data)


kf = kf.em(data, n_iter=5)
(filtered_state_means, filtered_state_covariances) = kf.filter(data)
(smoothed_state_means, smoothed_state_covariances) = kf.smooth(data)





fig = plt.figure(figsize=(20,10))



fig = plt.figure()
ax = fig.add_subplot(111)


ax.plot(x, data, label='raw sensor data')
ax.plot(x, mean, label='kalman mean')
ax.plot(x, filtered_state_means, label='em kalman filter mean')
ax.plot(x, smoothed_state_means, label='em kalman smoothed mean')


plt.legend()
plt.show()






# credits:
# https://pykalman.github.io/
# https://medium.com/@jaems33/understanding-kalman-filters-with-python-2310e87b8f48




data_raw = np.genfromtxt('/home/andreas/PycharmProjects/igem19-ethz-phage-hw-model/hardware/data/od_measurements.csv', delimiter=',')
data_x = [x[0] for x in data_raw]
data_y = [x[1] for x in data_raw]

kf = KalmanFilter(initial_state_mean=0, n_dim_obs=1)
(mean, covariance) = kf.filter(data_y)

fig = plt.figure()
ax = fig.add_subplot(111)

ax.plot(data_x, data_y, label='raw sensor data')
ax.plot(data_x, mean, label='kalman filterered sensor data')

plt.legend()
plt.show()



from sklearn.svm import SVR

# extract sensor values at time points of the external od sensor measurements
X = np.array([data[int(x)*2] for x in data_x])

# define measured values
y = mean #data_y

clf = SVR(gamma='scale', C=10000.0, epsilon=0.01)
clf.fit(X.reshape(-1, 1), y)


fig = plt.figure()
ax = fig.add_subplot(111)

ax.plot(data_x, data_y, label='external od sensor data')
ax.plot(data_x, X, label='online od sensor data')

plt.legend()
plt.show()

"""
fig = plt.figure()
ax = fig.add_subplot(111)
x2 = np.arange(0, 2.2e9, 1e7)
y2 = [clf.predict(x.reshape(-1,1)) for x in x2]
ax.plot(x2, y2, label='predicted data')
plt.legend()
plt.show()
"""

fig = plt.figure()
ax = fig.add_subplot(111)
x2 = np.arange(0, 2.2e9, 1e7)
y2 = [clf.predict(x.reshape(-1,1)) for x in x2]
ax.scatter(X, y, label="actual measurements")
plt.legend()
plt.show()


fig = plt.figure()
ax = fig.add_subplot(111)
x2 = np.arange(0, 2.2e9, 1e7)
y2 = [clf.predict(x.reshape(-1,1)) for x in x2]
ax.plot(x2, y2, label='predicted function')
ax.scatter(X, y, label="actual measurements")
plt.legend()
plt.show()


fig = plt.figure()
ax = fig.add_subplot(111)
x2 = np.arange(0, len(data))
y2 = [clf.predict(np.array(data[x]).reshape(-1, 1)) for x in x2]
ax.plot(x2, np.array(y2).ravel(), label='predicted data')
plt.legend()
plt.show()

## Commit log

2019-08-29 Create first model version with two hosts, temperature and LB dependency.
2019-09-04 Add dedicated temperature and lb dependency functions to each host.
2019-09-12 Initial implementation of the arduino i2c slave device controlling the three ESCs.
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2019-09-16 Move host to general namespace for reuse in the recombineering and yeast assembly model.
2019-09-16 Add comments and update model optimal temperature value.
2019-09-16 Add initial prototype code for fetching temperature sensor data from the 1-wire bus.
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2019-09-16 Add initial prototype implementation of the 16 channel PWM module.
2019-09-17 Add initial prototype implementation of the 8 channel I/O module.
2019-09-17 Add initial prototype implementation of the TSL2591 light sensor.
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2019-09-17 Add error message to debug serial.
    [esc_i2c.c]
2019-09-17 Set up all PWM devices with their default value.
2019-09-17 Add functionality to set/reset individual I/O ports.
    [PCF8574.py]
2019-09-17 Change port to met OD sensor LED config.
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2019-09-17 Rewrite esc call function to meet global api standard.
2019-09-17 Fix bugs and add comments.
    [ESC.py]
2019-09-17 Initial implementation of the PID temperature control system.
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2019-09-19 Add measured pid controller values for graph plotting
    [control_value34.csv, kd34.csv, ki34.csv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]
2019-09-19 Update pid controller parameters and structure to run correctly
2019-09-19 Add initial implementation of od sensor measurement loop.
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2019-09-19 Change gain and integration time of sensor to meet actual requirements.
2019-09-19 Add print log and light sensor read integration.
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2019-09-19 Switch led of in od sensor measurement procedure.
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2019-09-19 Add oversampling examples for analysis.
    [od_1os.csv, od_4os.csv]
2019-09-19 Add oversampling measurement for analysis.
    [od_8os.csv]
2019-09-20 Add manual optical density measurements for sensor calibration.
    [od_measurements.csv]
2019-09-20 Add automatic optical density measurements for calibration.
    [od.csv]
2019-09-20 Add comparison plots between raw sensor data and kalman filtered sensor data.
2019-09-20 Add oversampled raw measurement data.
    [od_4os.csv, od_8os.csv]
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2019-09-24 Replace absolute daytime through relative time in minutes.
    [od_measurements.csv]
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2019-09-25 Move files to new project structure folder.
    [control_value22.csv, control_value34.csv, control_value39.csv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]
2019-09-25 Add plots to check the integrity of the self-built od sensor calibration procedure.
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2019-09-25 Add pid plots to understand the temperature control systems correct functionality.
2019-09-25 Add initial implementation of ambient temperature and pressure measurement device BME230.
2019-09-25 Create initial implementation of the water temperature sensor device driver abstraction.
2019-09-25 Create initial implementation of the water pump driver.
2019-09-26 Implement thread-safety for the shared one-wire bus system.
2019-09-26 Add initial implementation of the BME280 ambient temperature and pressure sensor.
2019-09-26 Add class structure for the electronic speed controller (ESC).
2019-09-26 Create initial implementation of the i2c multiplexer driver.
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2019-09-26 Create initial implementation of the light sensor driver.
2019-09-26 Create initial implementation of the pc fan driver.
2019-09-26 Create initial implementation of the peristaltic pump driver.
2019-09-26 Add implementation of the water temperature sensor driver.
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2019-09-26 Restructure ESC for use in the driver level.
2019-09-26 Restructure PCF8574 for use in the driver level.
2019-09-26 Restructure TCA9548A for use in the driver level.
2019-09-26 Avoid naming conflict for import.
    [BME280.py, PCA9685.py]
2019-09-26 Adapt TSL2591 light sensor implementation for usage in the driver.
2019-09-26 Fix bug in differentiation of thread-safe and thread-unsafe execution paths.
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2019-09-26 Add i2c multiplexer switching functionality to the light sensor driver in a thread-safe manner.
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2019-09-27 Add initial implementation of the temperature control device.
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2019-09-27 Bug fix parameter default value.
    [ESC.py]
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2019-09-27 Add module import fix to water pump.
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2019-09-27 Investigate method not found error.
    [PCA9685.py]
2019-09-27 Fix device id functionality.
    [ESC.py]
2019-09-27 Fix bug in function call.
    [TSL2591.py]
2019-09-28 Implement threaded execution of the od sensor and temperature control event loops.
2019-09-28 Match all user input commands to the corresponding device function calls. Add device name to integer id mappings. Nest the whole command loop inside a try catch KeyboardInterrupt and handle proper pr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
2019-09-28 Make sure to stop the esc at initialization in case of enabled=False.
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2019-09-28 Fix wrong positioning of starttime.
    [reactor.py]
2019-09-28 Implement device functionality of the od sensor as well as the local run loop.
2019-09-28 Fix timestamp creation. Fix target setpoint for pid feedback controller.
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2019-09-29 Remove pump from mapping. Add finalization procedure. Fix missing parameter in instantiation.
    [reactor.py]
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2019-09-29 Fix module import issue. Standardise location of device id mapping.
    [ESC.py]
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2019-09-30 Add calibration data.
    [calibration_od_data.csv, calibration_sensor_data.csv]
2019-10-01 Fix import paths. Add hardware and hardware/devices to sys.path. Add print logging. Fix issue with check if data is available at stdin.
    [reactor.py]
2019-10-01 Fix import paths. Add hardware and hardware/devices to sys.path. Fix device id mapping. Fix od calibration model fitting routine. Add functionality to enable/disable the sensor.
2019-10-01 Fix import paths. Add hardware and hardware/devices to sys.path. Fix import naming conflict using an alias. Add print statements for verbose output.
2019-10-01 Fix import paths. Add hardware and hardware/devices to sys.path. Fix device id mapping for the ESC. Add water pump functionality. Print target temperature output. Fix positioning of try/catch in orde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
2019-10-01 Fix import paths. Change loop position since stopping has to be called only once.
    [ESC.py]
2019-10-01 Fix imports. Add default value for i2c lock. Fix bug of wrong call method name.
2019-10-01 Fix imports. Add default value for i2c lock. Add i2c multiplexer initialization call. Add 100ms wait time between i2c switch and reading from the sensor.
2019-10-01 Fix imports. Add default value for i2c lock. Change data type of id to int. Fix bug of parameter being float instead of int. Fix device id mapping.
2019-10-01 Fix imports. Add default value for i2c lock. Fix device id mapping. Fix bug of parameter being float instead of int. Shorten sleep time for faster observability.
2019-10-01 Add default value for i2c lock. Fix device id mapping. Fix bug of parameter being float instead of int.
2019-10-01 Fix import path. Fix device id mapping.
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2019-10-01 Remove code artifact. The proper initialization of the i2c multiplexer has to be done beforehand, since static classes are initialized automatically which breaks the functionality since no TSL2591 se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
2019-10-09 Fix controller help print statement. Use selected local pumps in the controller.
    [reactor.py]
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2019-10-09 Fix light sensor device mapping.
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2019-10-11 Implement output signal reset after a few rounds. This fixes communication issues that arise on the PPM protocol between the arduino and the ESCs.
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2019-10-15 Fix invisible text. Add arrows to event loop threads.
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2019-10-16 Fix bug with negative value.
    [main.py]
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2019-10-19 Move plotting data.
    [control_value22.csv, control_value34.csv, control_value39.csv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]
2019-10-19 Move data for generating plots.
    [calibration_od_data.csv, calibration_sensor_data.csv]
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2019-10-20 Add latest cad 3d printing designs to the repo.
    [cuvette_cover_v2.stl, erlenmeyer_stand_v1.stl, od_bottom_tsl2591_v5.stl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]
2019-10-28 Add experimental data.
    [growth_rate_ecor16_290.csv, growth_rate_ecor16_340.csv, growth_rate_ecor16_390.csv]
2019-10-28 Initial implementation and extension of the basic growth model with the following features: -conversion between OD600 and cell concentration -regression of growth rate experimental points -simulation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
2019-11-02 Add real device data.
    [2019-10-09_14_38_10_od2.csv, 2019-10-09_14_58_49_od2.csv, 2019-10-09_15_13_30_od2.csv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]

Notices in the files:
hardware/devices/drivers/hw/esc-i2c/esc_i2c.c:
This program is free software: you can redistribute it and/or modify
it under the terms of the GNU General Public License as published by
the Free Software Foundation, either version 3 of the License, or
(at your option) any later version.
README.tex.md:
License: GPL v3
